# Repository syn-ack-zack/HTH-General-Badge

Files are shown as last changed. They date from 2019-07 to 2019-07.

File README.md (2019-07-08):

## Hackers Teaching Hackers General Badge

##### Art Design and PCB Implementation: [mcm3nac3](https://twitter.com/mcm3nac3)

The general attendee badge for HTH 2019 was a PCB with the necessary circuit to allow for a USB or battery powered [Shitty Add-On (SAO)](https://hackaday.io/project/52950-shitty-add-ons) Totem badge supporting up to 4 diferent add-ons. The necessary components to enable your badge to be powered can be found in the bill of materials.   

Included in this repository are the necessary KiCad files for modifying this design and creating the necessary outputs for manufacturing. The gerber files for fabrication have been included as well for your convenience.

The bill of materials can be observed in the file `hth-gen-bom.csv`. A digikey cart can also be [viewed here](https://www.digikey.com/short/p9q0p7) which contains the necessary components to 'electrify' your badge.

*Note: An error exists in the traces around the switch for the badge. You must bridge the middle pins of the slide switch as seen in the bottom-right of the picture below.*



### Schematic


### Footprints


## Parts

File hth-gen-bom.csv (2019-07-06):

Index | Quantity | Part Number | Manufacturer Part Number | Description | Customer Reference | Available | Backorder | Unit Price | Extended Price USD
1 | 1 | 36-2462-ND | 2462 | BATTERY HOLDER AA 2 CELL PC PIN |  | 1 | 0 | 1.21000 | 1.21
2 | 1 | 401-2000-ND | JS202011AQN | SWITCH SLIDE DPDT 300MA 6V |  | 1 | 0 | 0.43000 | 0.43
3 | 1 | 609-4618-1-ND | 10118194-0001LF | CONN RCPT USB2.0 MICRO B SMD R/A |  | 1 | 0 | 0.42000 | 0.42
4 | 1 | 576-1274-1-ND | MIC5209-3.3YS-TR | IC REG LINEAR 3.3V 500MA SOT223 |  | 1 | 0 | 1.23000 | 1.23
5 | 1 | 1276-1034-1-ND | CL10A105KO8NNNC | CAP CER 1UF 16V X5R 0603 |  | 1 | 0 | 0.10000 | 0.10
6 | 1 | 1276-1031-1-ND | CL10B104MO8NNNC | CAP CER 0.1UF 16V X7R 0603 |  | 1 | 0 | 0.10000 | 0.10
7 | 2 | 1276-6769-1-ND | CL10X106MO8NRNC | CAP CER 10UF 16V X6S 0603 |  | 2 | 0 | 0.24000 | 0.48
8 | 1 | B140HWDICT-ND | B140HW-7 | DIODE SCHOTTKY 40V 1A SOD123 |  | 1 | 0 | 0.44000 | 0.44

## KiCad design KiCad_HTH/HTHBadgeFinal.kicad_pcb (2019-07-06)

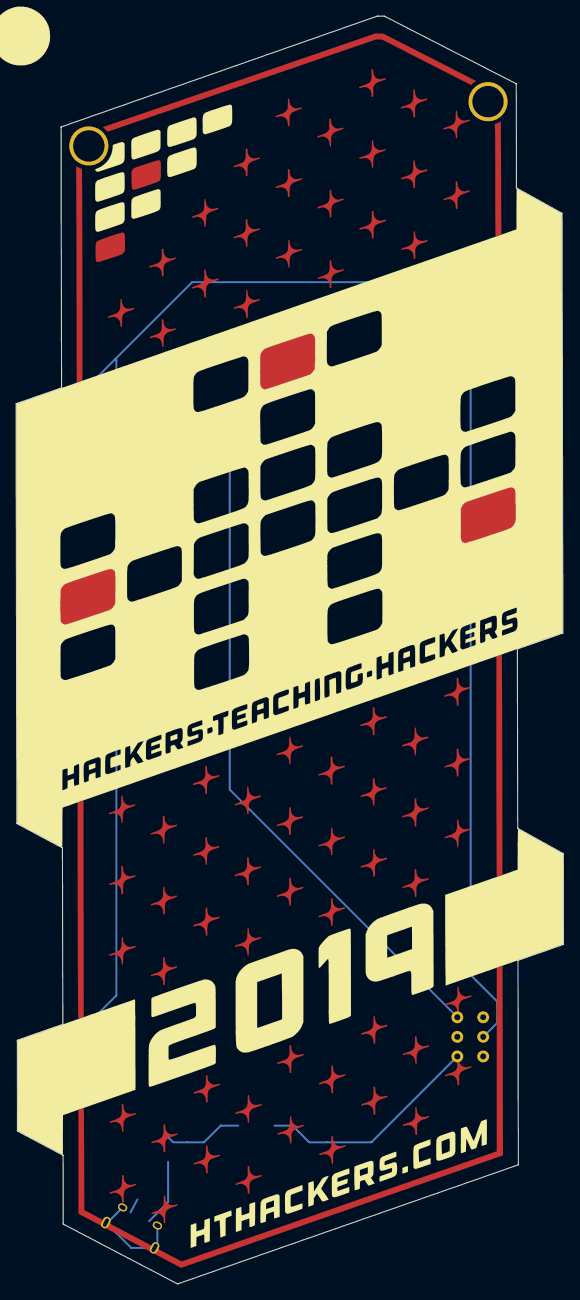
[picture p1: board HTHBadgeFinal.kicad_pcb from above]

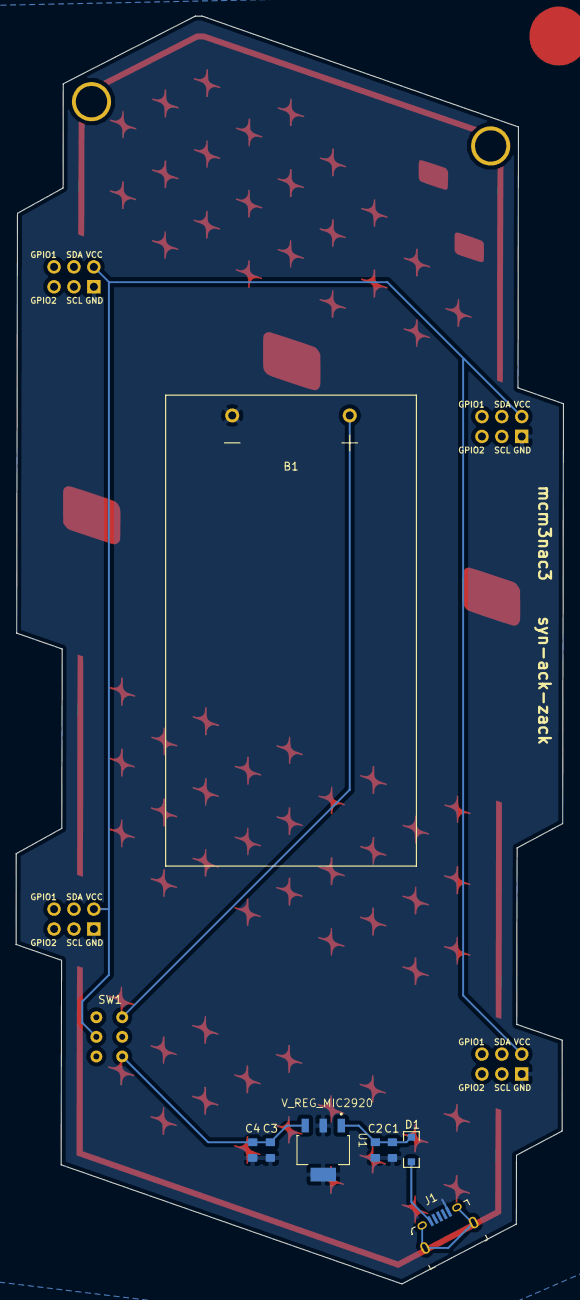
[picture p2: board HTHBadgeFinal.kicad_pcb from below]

Board: 2 copper layers, 69.8 x 161.8 mm, 13 parts (9 on the bottom side), 6 nets.

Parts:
B1: 2xAA; Keystone 2462 2xAA
C1, C4: CP1; CL10A105KO8NNNC
C2, C3: C; CL10A105KO8NNNC
D1: D_Schottky; B140HW-7
J1: 10118194-0001LF; USB_Micro_B_Female_10118194-0001LF
SW1: DPDT; JS202011AQN
U1: V_REG_MIC2920; SOT230P700X180-4N
X1, X2, X3, X4: Badgelife_sao_connector_v169bis; Badgelife-SAOv169-BADGE-2x3

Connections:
GND: B1.1, C1.2, C2.2, C3.2, C4.2, J1.5, U1.2, U1.4, X1.2, X2.2, X3.2, X4.2
unnamed: B1.2, SW1.4
unnamed: C1.1, C2.1, D1.1, U1.1
unnamed: C3.1, C4.1, SW1.6, U1.3
unnamed: D1.2, J1.1
unnamed: SW1.2, X1.1, X2.1, X3.1, X4.1
